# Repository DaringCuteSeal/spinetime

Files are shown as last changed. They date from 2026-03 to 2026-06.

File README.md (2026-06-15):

# Spinetime

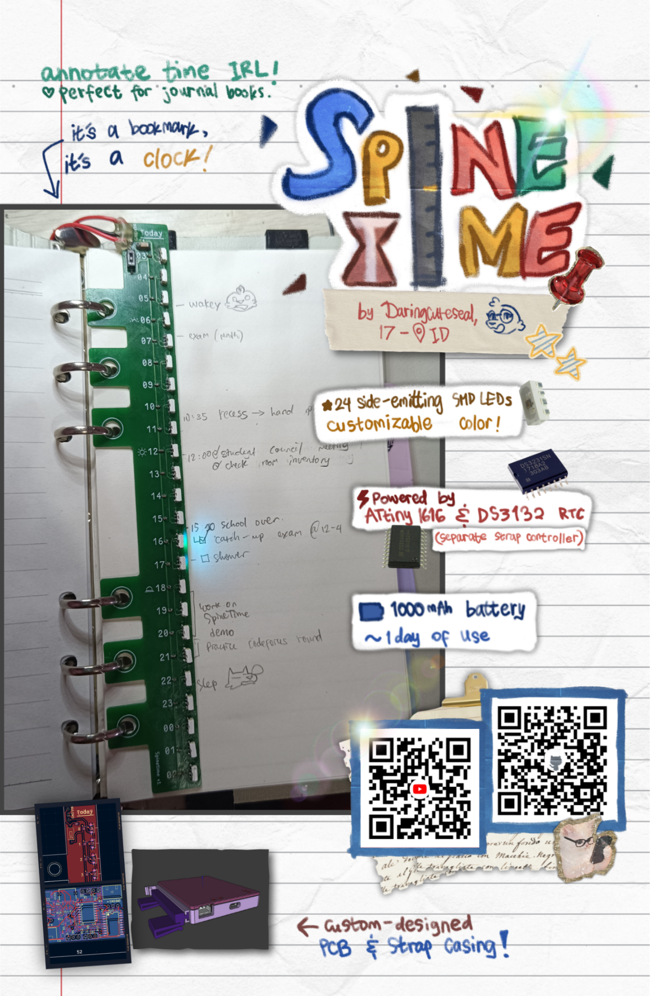
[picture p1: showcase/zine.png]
SpineTime magazine page

[Magazine PDF](showcase/zine.pdf)

[Watch the short demo here!](https://www.youtube.com/shorts/rvpcNDkeEeY)

---

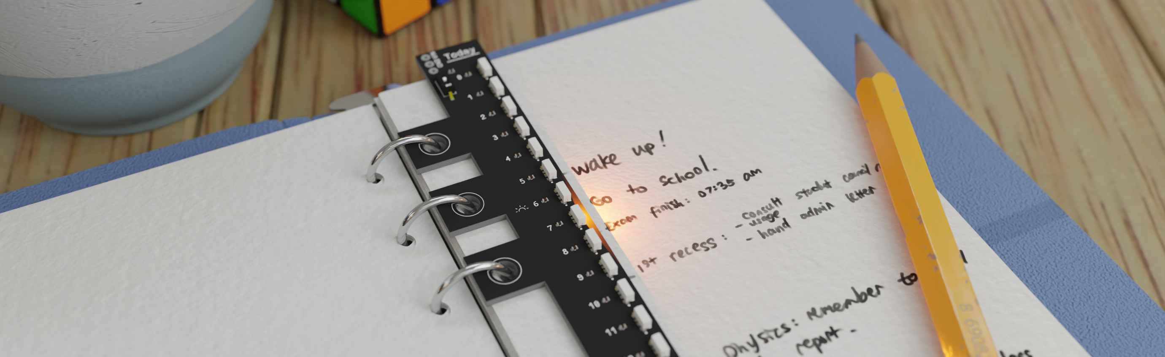
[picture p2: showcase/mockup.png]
Mockup of Spinetime


Spinetime is a ring binder-integrated _linear clock [^1]_ designed to help
students and neurodivergent individuals manage time and tasks more effectively.
Users of Spinetime can visualize the passage of the day at a glance, providing
aid especially for those who struggle with time blindness.

## Why?

It is surprising to me that people have manufactured papers with time table
template, but not invent something as simple as a pointer that tells you how
far you have gone through your table. I suspect that this is because most
people do not experience time blindness, and having some kind of pointer of the
table isn't really all that useful. This is simply not the case for those with
time blindness: **time doesn't really mean anything if presented in the wrong
way.** I hope that the proof of concept that came with Spinetime may help
present time meaningfully for those who struggle with time blindness like me.

## Background

As someone who suffers from time blindness on a daily basis, I find managing my
time extremely challenging. It's been intensely hard to picture how I'll spend
my time for a particular day. Having shuffled between multiple time management
methods, I constantly find myself at home when I plan my day out on my physical
journal. I simply love the tactile feel of using a physical tool to plan out my
day.

However, being the visual-oriented person I am, lacking any visual cue of
"where" in the time dimension I am at any given day has been a major
deal-breaker that has kept me from using physical tools for journalling. Of
course, journalling papers with pre-made time tables exist, but they don't tell
me what time it really is right now in any tangible manner relating to the table
itself—what a bummer.

I've been using [ChronoCat](https://chronocat.app/) (not affiliated) to manage
my time lately, and it's been a perfect digital tool—minimalistic,
very visual, and easy to use. It provides the user with a
time table alongside a visual cue of where they are within the day.
However, like I said before, I crave the tactile feel of physical
note-taking. It'd also be great if I can plan my day without the distraction
that comes with using a full-fledged mobile phone or computer.
Plus, being able to plan my day at school would be a great[^2]. I always
dream that one day, I won't forget several of my appointments again.

I looked at my own journalling book again, and thought: _you know, I
think that ChronoCat's approach doesn't have to be in the form of a
digital app._ And so, I came up with SpineTime.

## How to Use

**Daily use**: simply strap Spinetime to your ring binder by opening the spine and inserting
the linear clock component and start annotating your day. This repository hosts
the A6 binder-compatible
version.

**How to charge the battery**: charge with a type-C cable. 5V, obviously. The controller implements load sharing so you'll be powering the circuit directly with the given 5V when charged.

## How it Works
The LEDs of the bookmark are controlled by a separate controller unit. An ATtiny1616 MCU is used alongside a DS3231 RTC.

## Specs
- Power usage: about 20-25 mA when bookmark is on (3.7V * 25mA = 92.5 mW). Depends on LED color. 7 mA when bookmark is switched off (3.7V * 7mA = 25.9 mW).
- Use duration: about 1d 16h (1000 mAh ÷ 25 mA). Probably a bit lower since we won't (and can't) use the full capacity of the battery.

## Build Instruction
You will need:
1. A soldering iron
2. Solder
3. Everything from [BOM](#BOM)
4. A USB-to-TTL adapter such as a CH340 breakout module
5. Wire crimper
6. Wire stripper
7. Scissors
8. USB-C cable
9. 3 jumper wires (female-to-female)

Steps:
1. Print the [PCBs](#Project-Design-Showcase). Customize if needed. Note that the gerbers aren't included, so you'd have to generate them first from KiCad.
2. Solder components listed on the [BOM](#BOM) according to the PCB file.
3. 3D print the casing components.
4. Use whatever set of cables you have (can be thin) and solder the bookmark's VIN, GND, and DAT through-holes to the cables. Crimp the end into the 3-pin JST housing. Make sure the orientation is aligned correctly with the controller (as JST connectors cannot be plugged in both orientations).
5. Put together everything into the casing: the battery, the controller PCB, and the anti-slip rubbers (might need to be cut to the correct size first, fitting the casing's square indents).
6. If your battery hasn't been crimped yet, crimp the cables to the 2-pin JST. Then plug the battery connector to the controller.
7. Build the [firmware](#firmware). Customize as you wish. You'll need [PlatformIO](https://platformio.org/).
8. FLash the firmware. Initially, set `SET_TIME` to `true` in the `cfg.h` file first to set time, then flash again with `SET_TIME` set to `false`. You will need a USB-to-TTL adapter. Connect the TX pin of the adapter to the TX pin of SpineTime's controller PCB and the RX pin of the adapter to RX. Note that the PCB doesn't have labels for that.. just check the kicad file to know which is which :P. Then, connect the adapter's ground accordingly.
9. You should be done! There's no screw assembly required—everything uses compliant mechanism.

Gotchas:
1. If you can't flash the ATtiny1616, try changing to another device. Initially I couldn't flash my ATtiny and as it turns out, my laptop has a bad USB controller.
2. Some sources online say that SK6812 LEDs are difficult to solder and require lower temp but I found that with hand-soldering, even up to ~350°C is fine. (just don't roast the LEDs for 1 minute straight I guess)

## Spelling
Spinetime, SpineTime, spinetime are all valid. No spineTime or spine_time or anything else.
## Project Design Showcase

### IRL Build

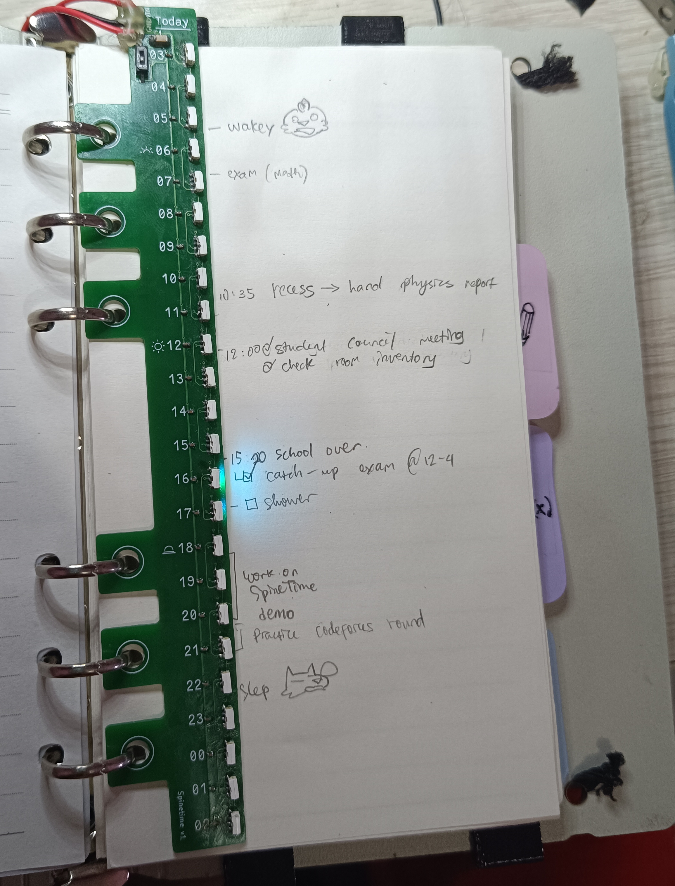
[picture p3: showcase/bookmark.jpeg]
Photo of the bookmark


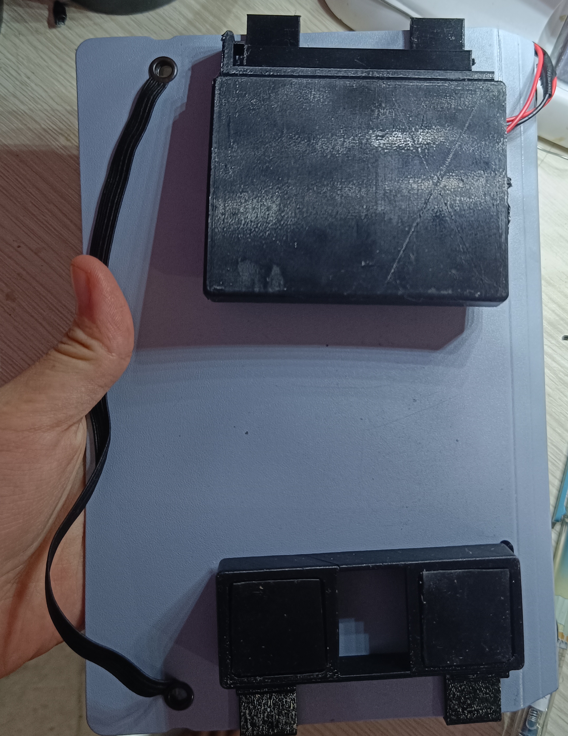
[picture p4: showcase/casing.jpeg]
Photo of the strap casing


Photo of the bookmark being used at a computer lab

Note: I built it with LEDs too big so I didn't put on the casing lid.

### PCBs

The actual bookmark ([project files](kicad/bookmark), [.step file](kicad/bookmark/bookmark.step)):

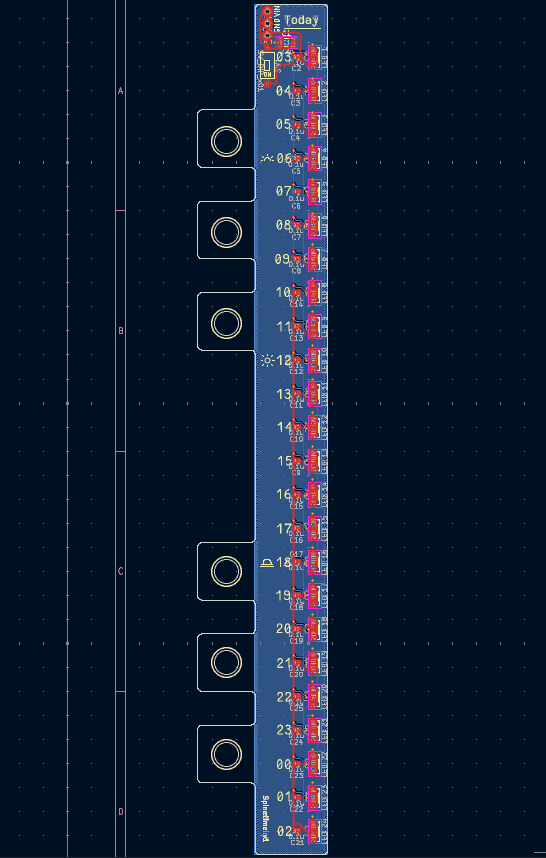
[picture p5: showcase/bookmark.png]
PCB design of bookmark


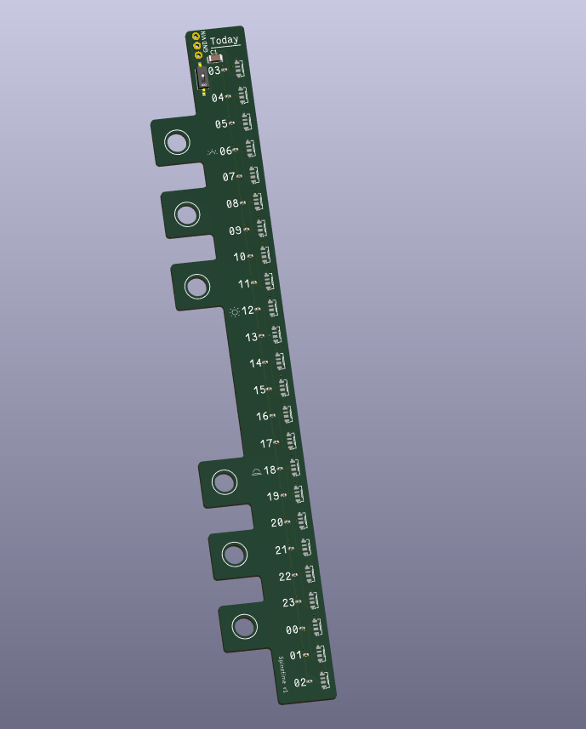
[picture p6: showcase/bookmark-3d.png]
3D PCB design of bookmark


The controller unit ([project files](kicad/controller), [.step file](kicad/controller/controller.step)):
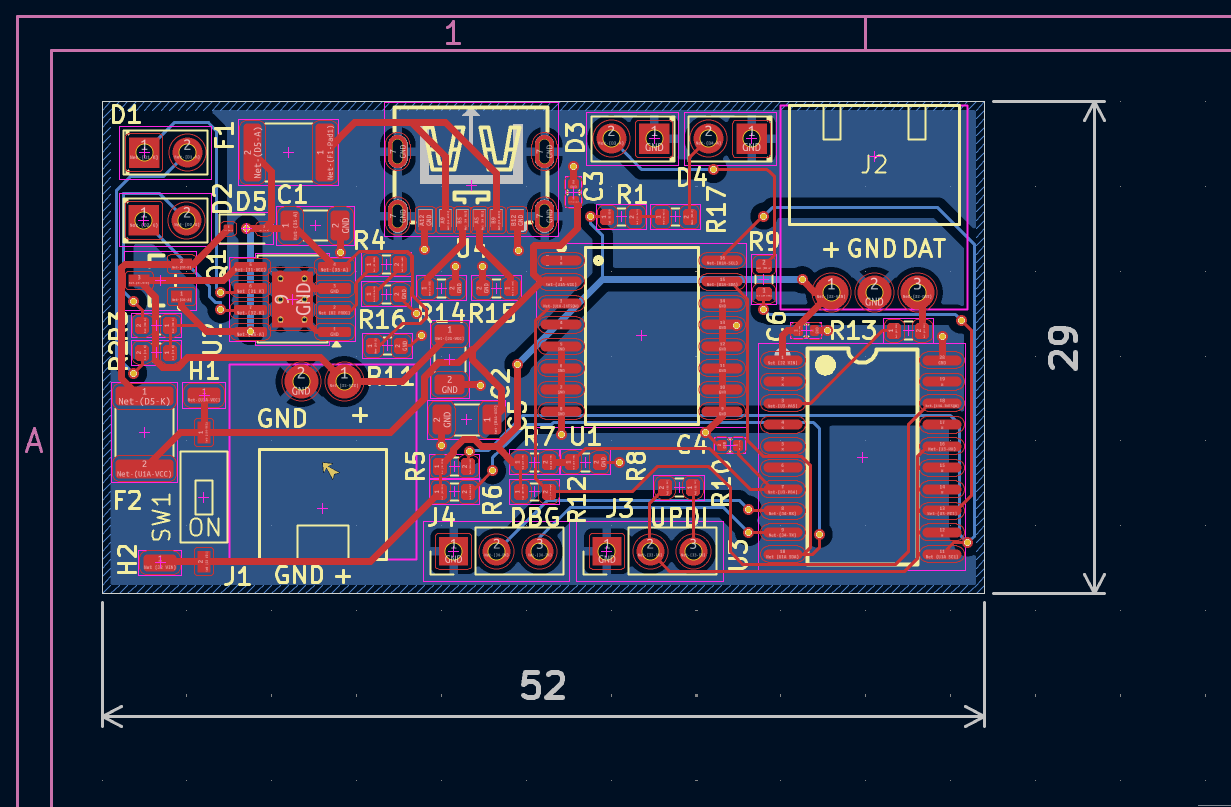
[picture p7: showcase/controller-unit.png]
PCB design of controller unit


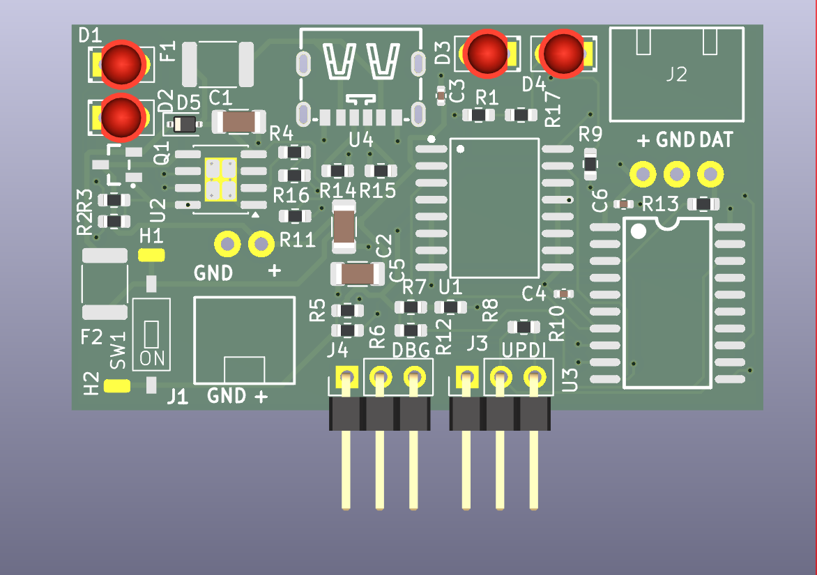
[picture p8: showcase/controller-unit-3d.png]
3D PCB design of controller unit


Schematics:

- [Schematic of controller unit](showcase/controller.pdf)
- [Schematic of bookmark unit](showcase/bookmark.pdf)

### 3D Models

The model files can be found under [freecad/](freecad/).

Casing:
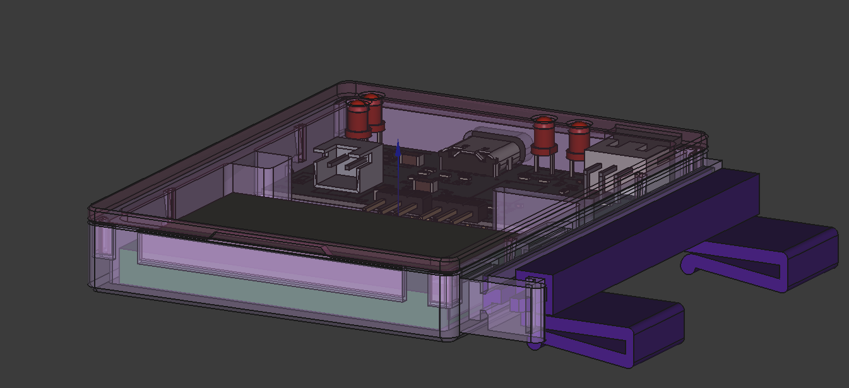
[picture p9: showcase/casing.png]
Casing 3D model


Support clip (so your book cover won't wobble when being written on):
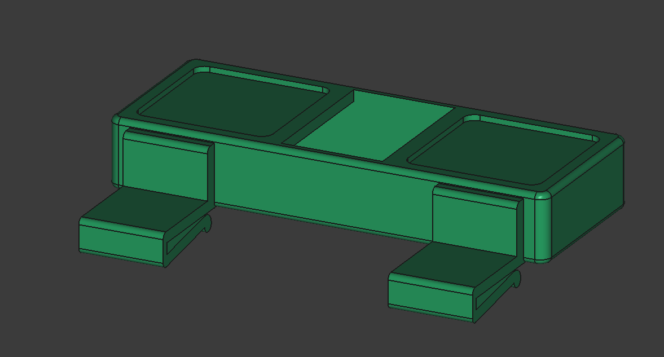
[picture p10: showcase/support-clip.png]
Support clip 3D model


### Firmware
The firmware files for SpineTime, `spinetime-fw`, can be [found in the firmware directory](./firmware).

## BOM
[BOM/bill of materials for this project can be found here](bom/bom.csv).

## Credits

Thanks to [Hack Club](https://hackclub.com/) for supporting! Initially made for [Hack Club Blueprint](https://blueprint.hackclub.com), but later got transferred to [Hack Club Fallout](https://fallout.hackclub.com/).

**Awesome software used:**
- [KiCad](https://www.kicad.org/) (as EDA)
- [Blender](https://www.blender.org/) (for designing mockup)
- [FreeCAD](https://www.freecad.org/) (as CAD)
- [NeoVim](https://neovim.io/) (as IDE)
- [VSCode](https://code.visualstudio.com/) (as IDE)
- [PlatformIO](https://platformio.org/) (as embedded programming platform)
- [Kitty](https://sw.kovidgoyal.net/kitty/) (as terminal)
- [Git](https://git-scm.com/) (as SVC)
- [Artix Linux!](https://artixlinux.org)

**Awesome services used:**
- [Github](.) (hosting project files)

**I used several 3D models for my PCB 3D model:**
- https://grabcad.com/library/usb-type-c-smd-6pin-1
- https://grabcad.com/library/2-pins-jst-1
- https://grabcad.com/library/3-pins-jst-1

**References (unfortunately not all, just the very notable ones):**
- megaTinyCore, awesome core + documentations for my ATTiny: https://github.com/SpenceKonde/megaTinyCore)
- Datasheet of all components I used. I'm not sure if I wanna include all of the links back because I didn't keep track of them, but feel free to ask for the documents I have locally directly to maybe figure out the source.
- NeoPixel guide: https://learn.adafruit.com/adafruit-neopixel-uberguide/logic-level
- Another NeoPixel guide: https://www.digikey.com/en/maker/projects/adafruit-neopixel-berguide/970445a726c1438a9023c1e78c42e0bb
- How to flash ATtiny1616: https://michael-crum.com/attiny1616/
- Changing clock speed of ATtiny1616: https://www.avrfreaks.net/s/topic/a5C3l000000Ubn4EAC/t159058
- Technical problems with SK6812: https://forums.adafruit.com/viewtopic.php?t=188940
- Sk6812 is hard to solder?: https://www.makerfabs.com/blog/post/how-makerfabs-solve-the-oled-sticking-problem
- Order with moisture-sensitive devices recommendations: https://jlcpcb.com/help/article/moisture-sensitivity-level-msl-for-electronic-parts
- Load-sharing circuit: https://www.thanassis.space/loadsharing.html
- SMD resistor guide: https://www.allpcb.com/blog/pcb-assembly/smd-resistors-demystified-sizes-markings-and-practical-applications.html
- Should LED strip's end be connected to anything?: https://www.reddit.com/r/AskElectronics/comments/1bnx4vv/addressable_led_data_out_connect_to_ground_yn/
- TP4056 breakout reference: https://github.com/alltheworld/tp4056/issues/3
- Setting internal reference voltage for attiny1616: https://forum.arduino.cc/t/how-to-measure-supply-voltage-in-attiny/1244260

Huh, am I over-crediting? maybe..
## LLM Usage Disclosure
I used [ChatGPT](https://chatgpt.com) for sanity-checking my configurations (including my controller schematic, for instance it caught that I didn't pull the CC pins to ground).

[^1]: Analog clock that shows time in a linear format, instead of the usual
12-hour wrap-around style. This clock is often suggested for those with ADHD &
time blindness.

[^2]: My school does not allow the use of mobile phone/laptop during class and
recess.

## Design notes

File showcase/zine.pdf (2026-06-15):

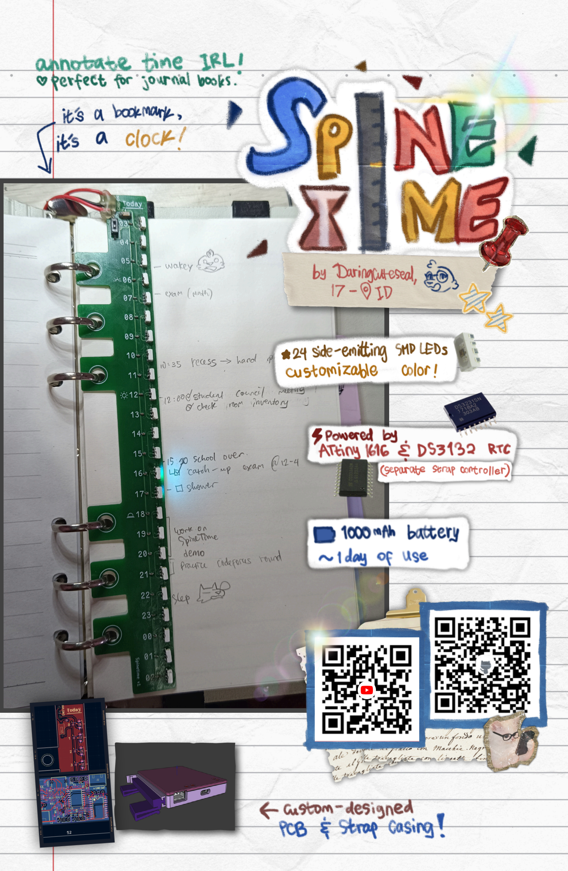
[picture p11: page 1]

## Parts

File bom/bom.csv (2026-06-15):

Index | LCSC# | MPN | Manufacturer | Package | Description | RoHS | Needed | Order Quantity | MOQ | Multiple | Unit Price | Extended Price | Product Link | Already Owned by Daringcuteseal | Note
1 | C382139 | TP4056 | TPOWER | ESOP-8 | Lithium-ion/Polymer ESOP-8 | TRUE | 1 | 5 | 5 | 5 | $0.11830 | $0.59 | https://www.lcsc.com/product-detail/C382139.html | FALSE
2 | C2927026 | USB-TYPE-C-006 | DEALON | SMD | USB-C (USB TYPE-C) Receptacle Connector 6 Position Surface Mount, Right Angle | TRUE | 1 | 10 | 10 | 10 | 9 | $0.49 | https://www.lcsc.com/product-detail/C2927026.html | FALSE
3 | C2830320 | FS8205A | TECH PUBLIC | SOT-23-6 | 20V 9A 1.5W Surface Mount SOT-23-6 | TRUE | 1 | 10 | 10 | 10 | $0.04710 | $0.47 | https://www.lcsc.com/product-detail/C2830320.html | FALSE
4 | C22366440 | DMP1045U-HXY | HXY MOSFET | SOT-23 | P-Channel 20V 5A 1.4W Surface Mount SOT-23 | TRUE | 1 | 10 | 10 | 10 | $0.06240 | $0.62 | https://www.lcsc.com/product-detail/C22366440.html | FALSE
5 | C20996 | SMD1812P075TF | RUILON | 1812 | Polymeric PTC Resettable Fuse 13.2V 750mA Surface Mount 1812 | TRUE | 1 | 5 | 5 | 5 | $0.08730 | $0.44 | https://www.lcsc.com/product-detail/C20996.html | FALSE
6 | C15008 | CL31A107MQHNNNE | Samsung Electro-Mechanics | 1206 | 100uF ±20% 6.3V Ceramic Capacitor X5R 1206 | TRUE | 3 | 10 | 10 | 10 | $0.06810 | $0.68 | https://www.lcsc.com/product-detail/C15008.html | FALSE
7 | C2100 | 1SS404 | JSCJ | SOD-323 | Diode 20V 300mA Surface Mount SOD-323 | TRUE | 1 | 20 | 20 | 20 | $0.0807 | $0.81 | https://www.lcsc.com/product-detail/C2100.html | FALSE
8 | C2937639 | SMD1812P020TF | PTTC(Polytronics Tech) | 1812 | Polymeric PTC Resettable Fuse 30V 200mA Surface Mount 1812 | TRUE | 1 | 10 | 10 | 10 | $0.08940 | $0.89 | https://www.lcsc.com/product-detail/C2937639.html | FALSE
9 | C15401 | 0603WAJ0103T5E | UNI-ROYAL | 603 | 10kΩ ±5% 100mW 0603 Thick Film Resistor | TRUE | 3 | 100 | 100 | 100 | $0.0012 | $0.12 | https://www.lcsc.com/product-detail/C15401.html | FALSE
10 | C23186 | 0603WAF5101T5E | UNI-ROYAL | 603 | 5.1kΩ ±1% 100mW 0603 Thick Film Resistor | TRUE | 2 | 100 | 100 | 100 | $0.00160 | $0.16 | https://www.lcsc.com/product-detail/C23186.html | FALSE
11 | C14675 | RC0603FR-07100KL | YAGEO | 603 | 100mW 100kΩ 75V Thick Film Resistor ±100ppm/℃ ±1% 0603 Chip Resistor - Surface Mount RoHS | TRUE | 1 | 100 | 100 | 100 | $0.00140 | $0.14 | https://www.lcsc.com/product-detail/C14675.html | FALSE
12 | C2890037 | SK6812SIDE-A-RVS | OPSCO Optoelectronics | SMD-4P,4x2mm | SMD-4P,4x2mm LED Addressable, Specialty RoHS | TRUE | 24 | 30 | 5 | 5 | $0.0935 | $2.81 | https://www.lcsc.com/product-detail/C2890037.html | FALSE | Have to buy slightly more than needed. Apparently they’re pain to solder (can break easily when overheated).
13 | C2680613 | CHS-01TB | Nidec | SMD | Dip Switch SPST 1 Position 100mA 6V | TRUE | 2 | 2 | 1 | 1 | $0.97000 | $1.94 | https://www.lcsc.com/product-detail/C2680613.html | FALSE
14 | C2907002 | FRC0603F1001TS | FOJAN | 603 | 1kΩ ±1% 100mW 0603 Thick Film Resistor | TRUE | 6 | 100 | 100 | 100 | $0.00100 | $0.10 | https://www.lcsc.com/product-detail/C2907002.html | FALSE
15 | C614136 | ATTINY1616-SN | MICROCHIP | SOIC-20-300mil | AVR 8 Bit 20MHz 18 SOIC-20-300mil Microcontrollers RoHS | TRUE | 1 | 1 | 1 | 1 | $2.70710 | $2.71 | https://www.lcsc.com/product-detail/C614136.html | FALSE
16 | C9866 | DS3231SN#T&R | MAXIM | SOIC-16-300mil | Built-in Yes SOIC-16-300mil Real Time Clocks RoHS | TRUE | 1 | 1 | 1 | 1 | $5.3424 | $5.34 | https://www.lcsc.com/product-detail/C9866.html | FALSE
17 | C105875 | RC0402FR-07330RL | YAGEO | 402 | 330Ω 62.5mW 50V Thick Film Resistor ±100ppm/℃ ±1% 0402 Chip Resistor - Surface Mount RoHS | TRUE | 1 | 100 | 100 | 100 | 0.0009 | $0.09 | https://www.lcsc.com/product-detail/C105875.html | FALSE
18 | C51048328 | FRC0603F7873TS | FOJAN | 603 | 100mW 787kΩ 75V Thick Film Resistor ±400ppm/℃ ±1% 0603 Chip Resistor - Surface Mount RoHS | TRUE | 1 | 100 | 100 | 100 | 0.0012 | $0.12 | https://www.lcsc.com/product-detail/C51048328.html | FALSE
19 | C2906866 | FRC0402F2003TS | FOJAN | 402 | 200kΩ ±1% 62.5mW 0402 Thick Film Resistor | TRUE | 1 | 100 | 100 | 100 | 0.0007 | $0.07 | https://www.lcsc.com/product-detail/C2906866.html | FALSE
20 | C60474 | CC0402KRX7R7BB104 | YAGEO | 402 | 100nF ±10% 16V Ceramic Capacitor X7R 0402 | TRUE | 27 | 100 | 100 | 100 | $0.00110 | $0.11 | https://www.lcsc.com/product-detail/C60474.html | FALSE
21 |  |  | JLCPCB | 27*177 mm^2 | Bookmark FR4 PCB printing: 27 mm*177 mm, Industrial/Consumer electronics, single PCB, no stackup, white silkscreen, tented via covering, deburring, without gold fingers, without castellated holes, no PCB marking, IPC class 2 standard appearance quality, ink-jet/screen printing silkscreen, without inspection report, without humidity indicator card, 3d build time, 1 layer, 1 design, 1mm thickness, green color, FR4 TG135 material, leaded HASL surface finish, 1 oz outer copper weight, without electrical testing, without edge plating, without paper between PCBs, without confirmation of production file, package box with JLCPCB logo, without UL marking. | FALSE | 1 | 5 | 5 | 5 | unavailable | $5.90 | https://jlcpcb.com/pcb-fabrication/fr4-pcb | FALSE
22 |  |  | JLCPCB | 52*29 mm^2 | Controller unit FR4 PCB printing: 52 mm*29 mm, Industrial/Consumer electronics, single PCB, no stackup, white silkscreen, tented via covering, deburring, without gold fingers, without castellated holes, no PCB marking, 0.3 mm/(0.4/0.45 mm) minimum via hole size/diameter, without 4-wire Kelvin Test, IPC class 2 standard appearance quality, ink-jet/screen printing silkscreen, without inspection report, without humidity indicator card, 2d build time, 2 layers, 1 design, 0.8mm thickness, green color, FR4 TG135 material, leaded HASL surface finish, 1 oz outer copper weight, without electrical testing, without edge plating, without blind slot, without paper between PCBs, without confirmation of production file, package box with JLCPCB logo, board ± 0.2mm outline tolerance, without countersink hole, without UL marking. | FALSE | 1 | 5 | 5 | 5 | unavailable | $2.10 | https://jlcpcb.com/pcb-fabrication/fr4-pcb | FALSE
23 |  |  | Unknown | 523450 | 1000 mAh 523450 3.7V li-po battery with built-in BMS | Unknown | 1 | 1 | 1 | 1 | Rp79,900 | Rp79,900 | https://shopee.co.id/product/19839879/26426877851 | FALSE
24 |  |  | Unknown | XH2.54 | Right-angled 2.54 pitch JST connector, 2 pins | Unknown | 1 | 70 | 70 | 1 | Rp300 | Rp21,000 | https://shopee.co.id/product/46203672/18744978386 | TRUE
25 |  |  | Unknown | XH2.54 | Right-angled 2.54 pitch JST connector, 3 pins | Unknown | 1 | 70 | 70 | 1 | Rp300 | Rp21,000 | https://shopee.co.id/product/46203672/19344978895 | TRUE
26 |  |  | Unknown | 3mm THT | 3mm diffused LED red (used for charging indicator and power indicator) | Unknown | 2 | 10 | 10 | 1 | Rp250 | Rp2,500 | https://shopee.co.id/product/2178321/3603345969/ | TRUE
27 |  |  | Unknown | 3mm THT | 3mm diffused LED yellow (used for low battery warning and debugging) | Unknown | 1 | 10 | 10 | 1 | Rp250 | Rp2,500 | https://shopee.co.id/product/2178321/294292043/ | TRUE
28 |  |  | Unknown | 3mm THT | 3mm diffused LED green (used for full battery indicator) | Unknown | 1 | 10 | 10 | 1 | Rp250 | Rp2,500 | https://shopee.co.id/product/2178321/3603345974/ | TRUE
29 |  |  | Unknown | 5cm*5cm | Rubber sheet for anti-slipping | Unknown | 1 | 7 | 7 | 1 | Rp1,527 | Rp10,689 | https://shopee.co.id/product/274611018/28530490992 | FALSE
30 |  |  | PegangInd |  | 3D printing service with PETG filament | Unknown | 39 | 39 | 1 | 1 | Rp799 | Rp31,161 | https://shopee.co.id/product/234204219/26236129391 | FALSE | Nice cheap local printing service. Price is in per gram of filament (includes extra filament for support).
31 |  |  |  |  | Shipping fee (SF International Standard Express) |  |  |  |  |  | $23.99 | $23.99

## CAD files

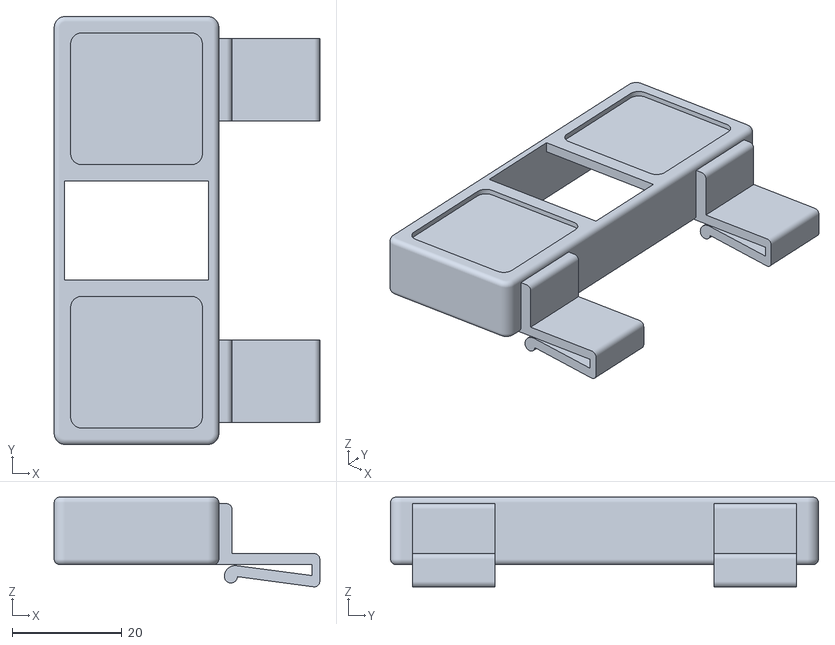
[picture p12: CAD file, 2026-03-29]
freecad/support-clip.stl
48.4 x 78.0 x 16.4

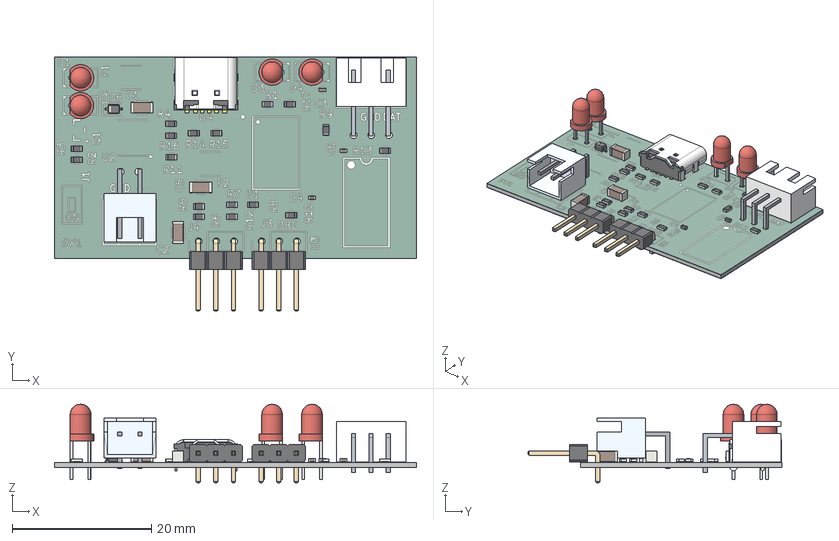
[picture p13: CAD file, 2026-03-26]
kicad/controller/controller.step
52.0 x 36.5 x 11.3 mm
Bileşen1
Bileşen3
Bileşen004
LED_D3.0mm x 4
PinHeader_1x03_P2.54mm_Horizontal x 2
R_0603_1608Metric x 17
D_SOD-323
C_1206_3216Metric x 3
Bileşen008
Bileşen009
Bileşen2.001
Bileşen010
C_0402_1005Metric x 3
USB_type_C_smd_6p
controller_silkscreen
controller_soldermask x 2
controller_PCB

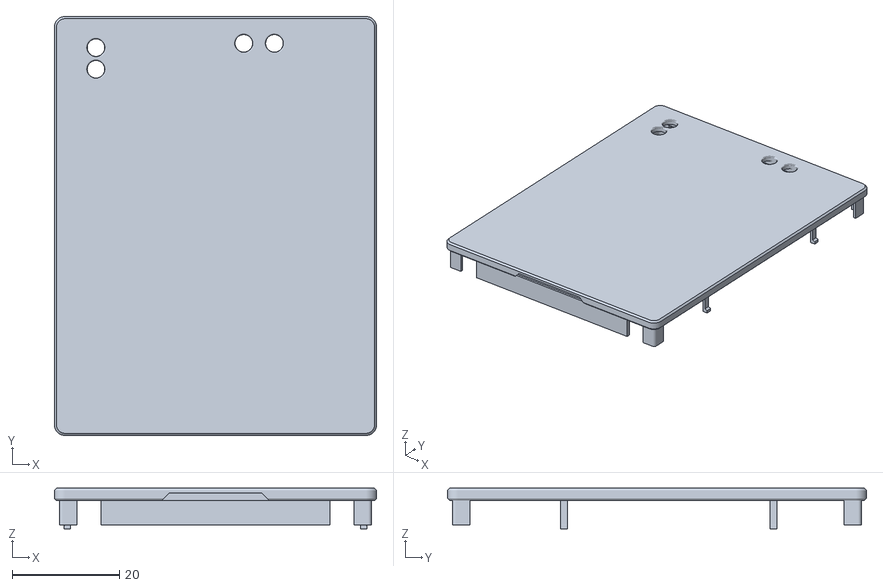
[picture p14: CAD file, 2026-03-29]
freecad/lid.stl
60.0 x 78.0 x 7.58

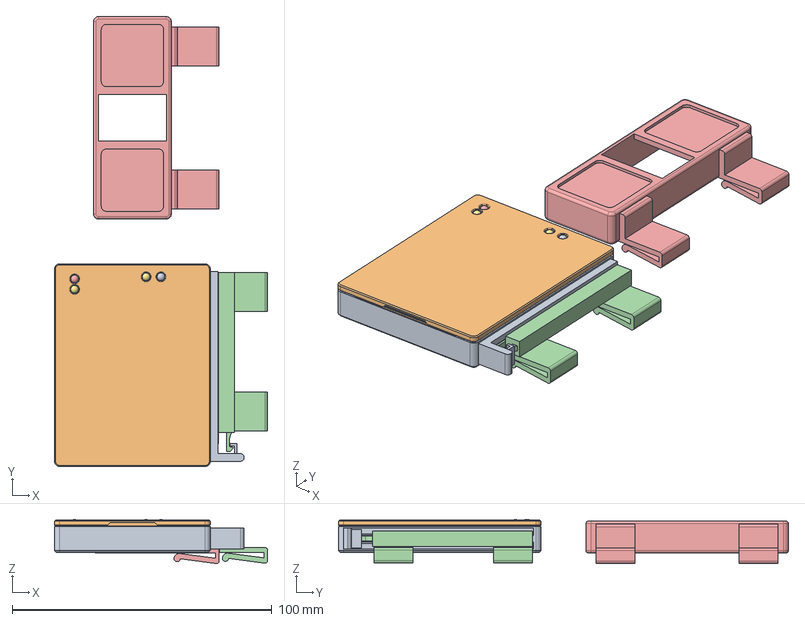
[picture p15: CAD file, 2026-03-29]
freecad/models.FCStd
82.0 x 173.2 x 17.0 mm
casing
lid
battery
BileÃ Âen1
BileÃ Âen3
BileÃ Âen004
LED_D3.0mm
PinHeader_1x03_P2.54mm_Horizontal
LED_D3.0mm001
R_0603_1608Metric
R_0603_1608Metric001
R_0603_1608Metric002
R_0603_1608Metric003
R_0603_1608Metric004
R_0603_1608Metric005
PinHeader_1x03_P2.54mm_Horizontal001
D_SOD-323
R_0603_1608Metric006
R_0603_1608Metric007
C_1206_3216Metric
LED_D3.0mm002
BileÃ Âen008
BileÃ Âen009
BileÃ Âen2.001
BileÃ Âen010
C_0402_1005Metric
R_0603_1608Metric008
R_0603_1608Metric009
R_0603_1608Metric010
C_0402_1005Metric001
LED_D3.0mm003
R_0603_1608Metric011
R_0603_1608Metric012
R_0603_1608Metric013
USB_type_C_smd_6p
USB_type_C_smd_6p001
USB_type_C_smd_6p002
USB_type_C_smd_6p003
C_1206_3216Metric001
R_0603_1608Metric014
R_0603_1608Metric015
R_0603_1608Metric016
C_0402_1005Metric002
C_1206_3216Metric002
controller_silkscreen
controller_silkscreen001
controller_silkscreen002
controller_silkscreen003
controller_silkscreen004
controller_silkscreen005
controller_silkscreen006
controller_silkscreen007
controller_silkscreen008
controller_silkscreen009
controller_silkscreen010
controller_silkscreen011
controller_silkscreen012
controller_silkscreen013
controller_silkscreen014
controller_silkscreen015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

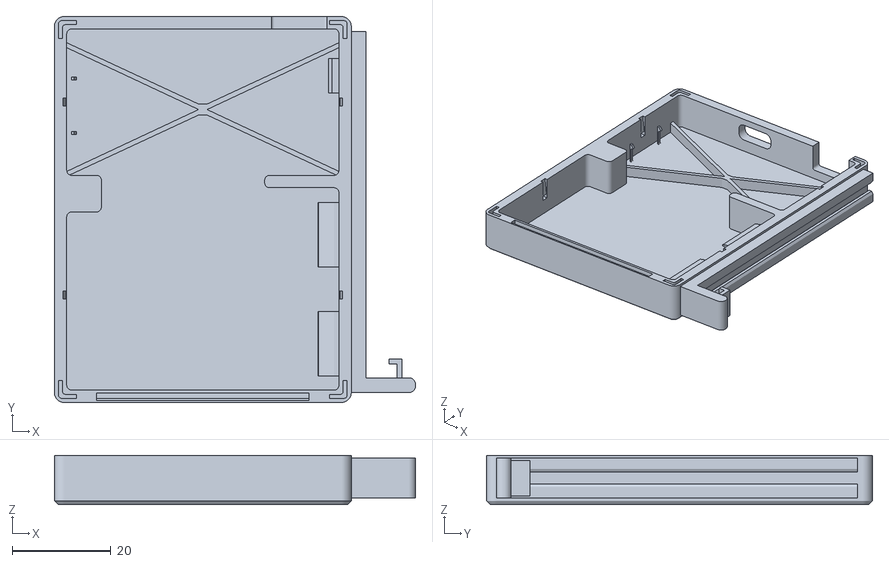
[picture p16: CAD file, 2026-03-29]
freecad/casing.stl
73.0 x 78.0 x 10.0

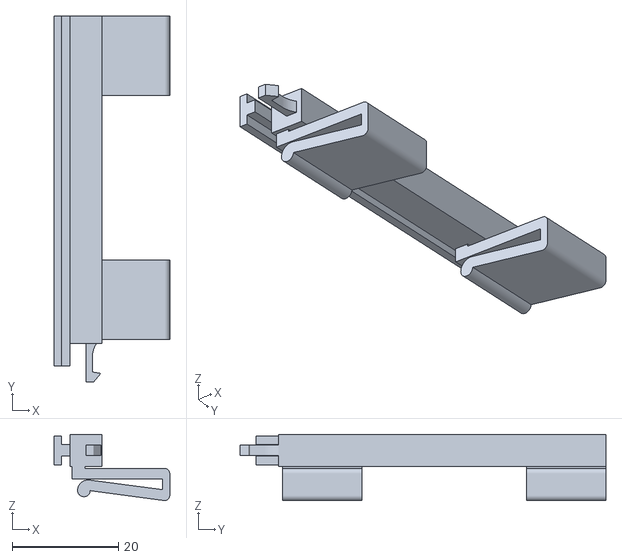
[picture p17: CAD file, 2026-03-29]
freecad/casing-clip.stl
21.8 x 69.0 x 12.5

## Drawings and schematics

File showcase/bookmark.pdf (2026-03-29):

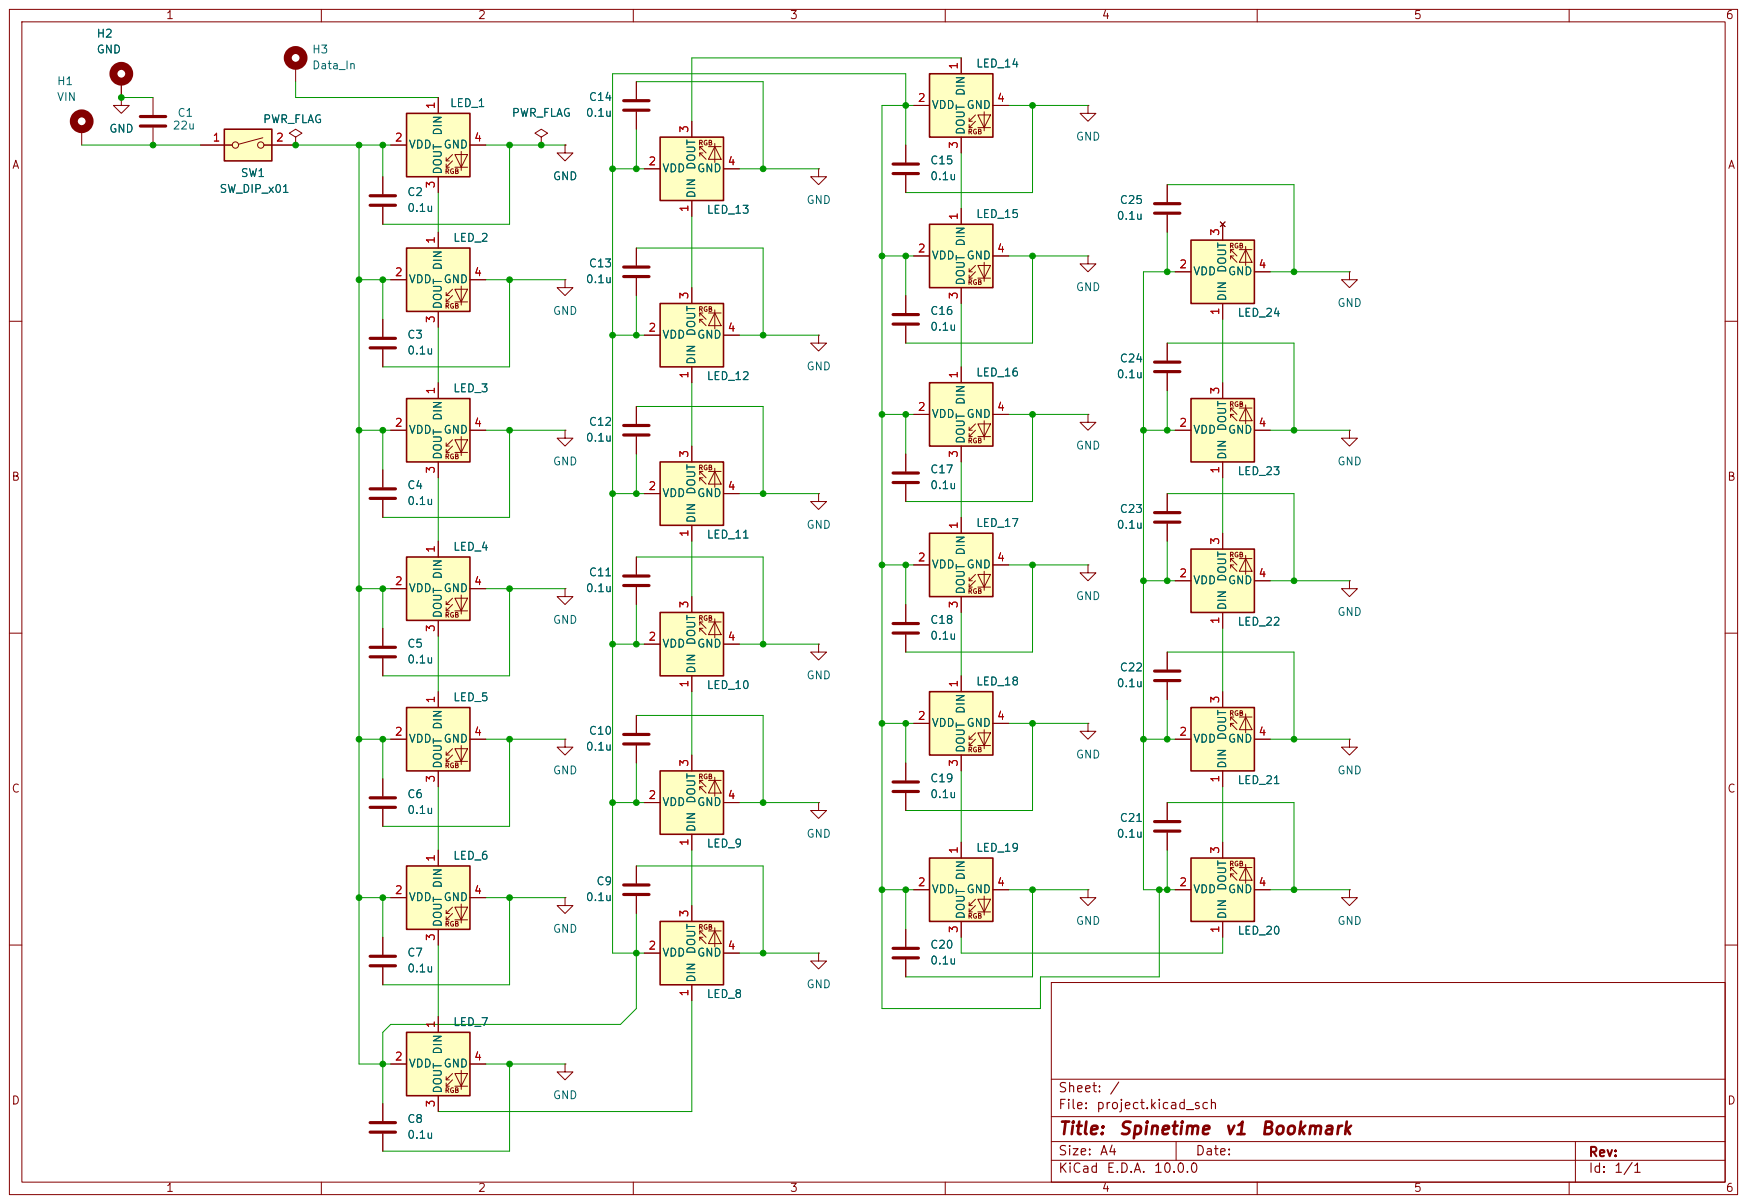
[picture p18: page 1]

Size: A4 | Rev:
KiCad E.D.A. 10.0.0 | Id: 1/1

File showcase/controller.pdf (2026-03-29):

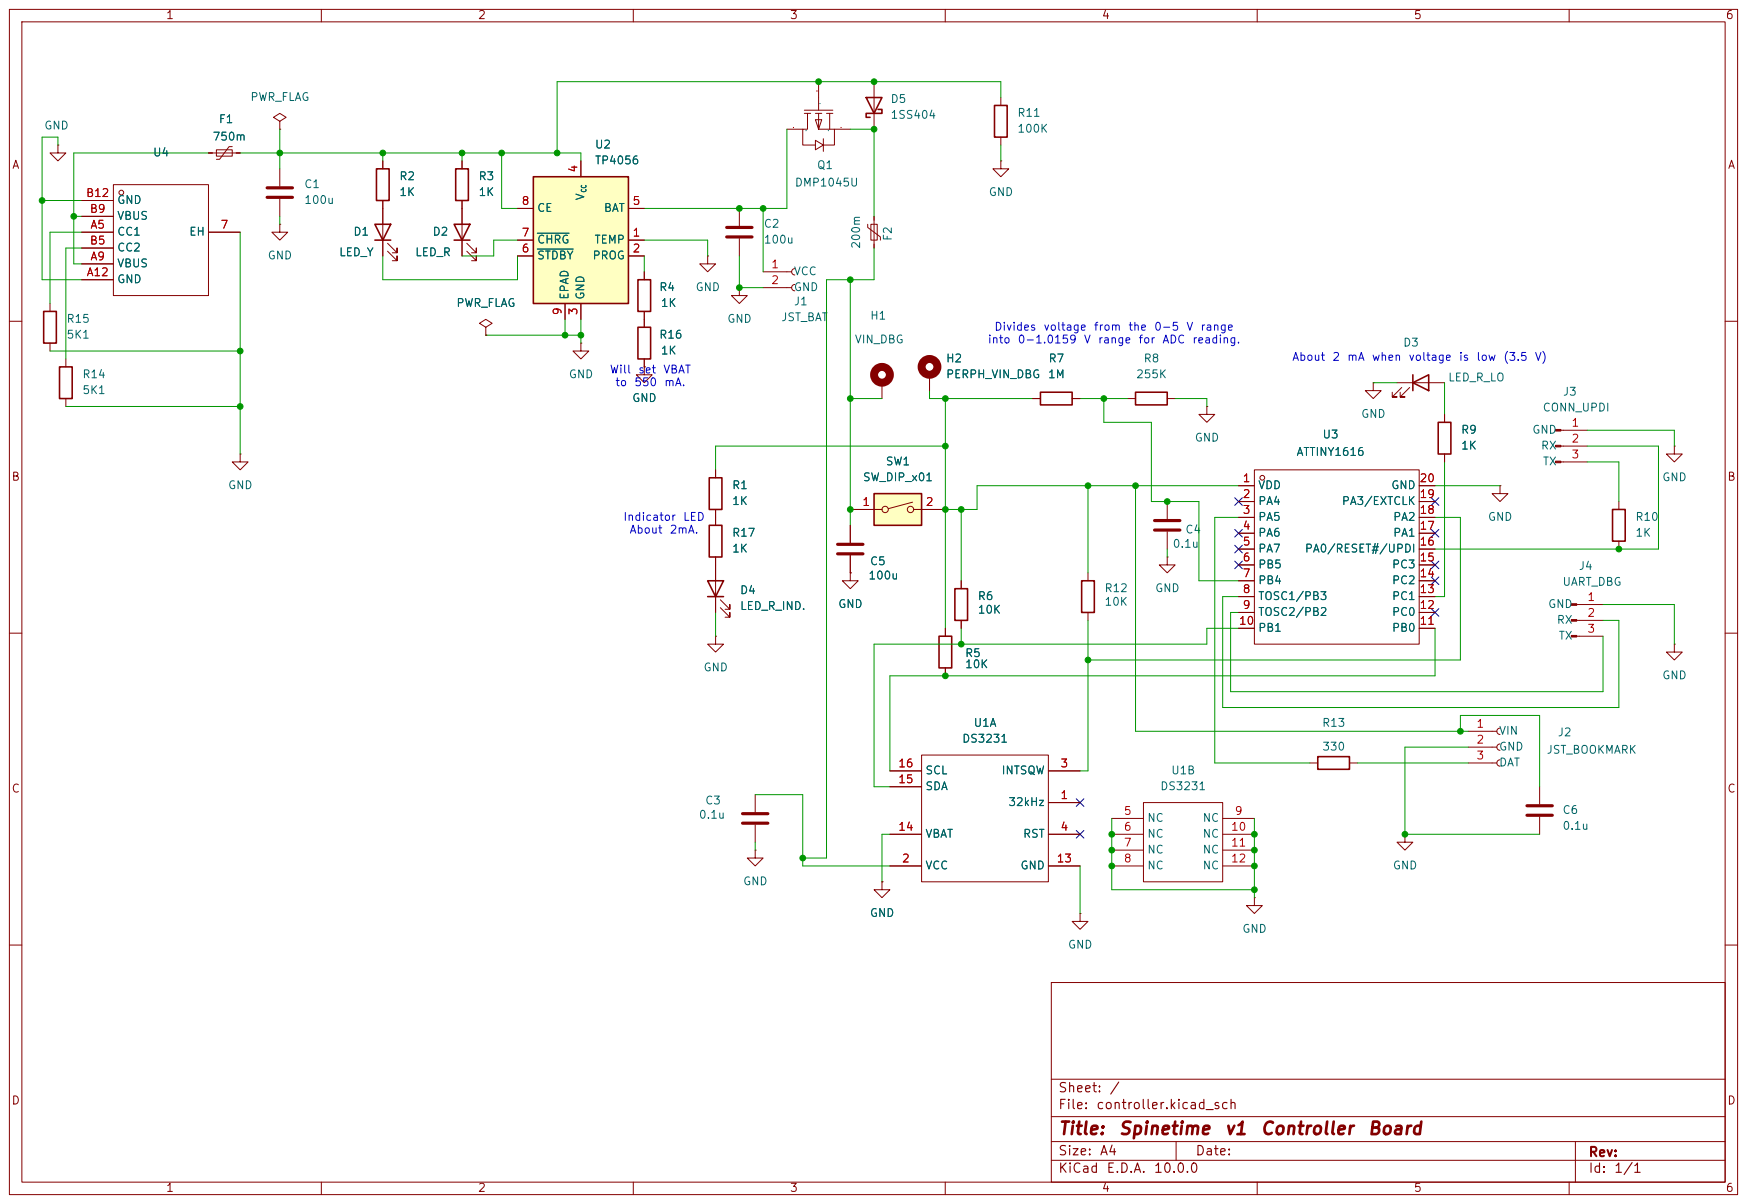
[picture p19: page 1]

Divides voltage from the 0-5 V range
into 0-1.0159 V range for ADC reading.

About 2 mA when voltage is low (3.5 V)

About 2mA. Will set VBAT

Sheet: /
File: controller.kicad_sch
Title: Spinetime v1 Controller Board

Size: A4 | Rev:
KiCad E.D.A. 10.0.0 | Id: 1/1

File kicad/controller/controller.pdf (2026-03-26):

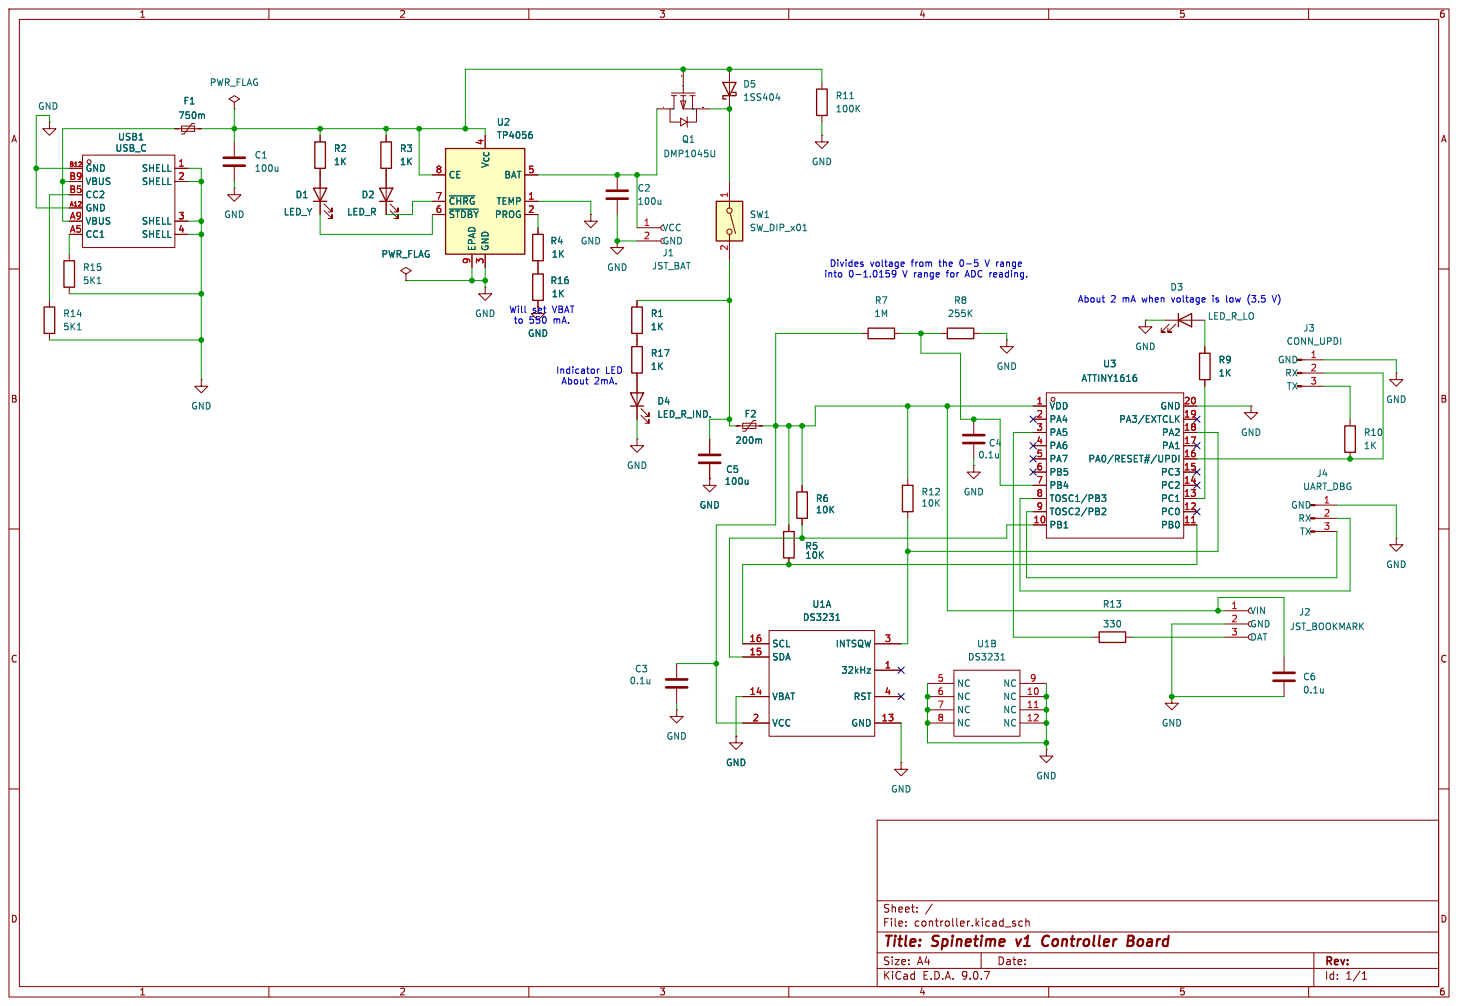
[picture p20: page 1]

File: controller.kicad_sch Sheet: /
Id: 1/1 Title: Spinetime v1 Controller Board

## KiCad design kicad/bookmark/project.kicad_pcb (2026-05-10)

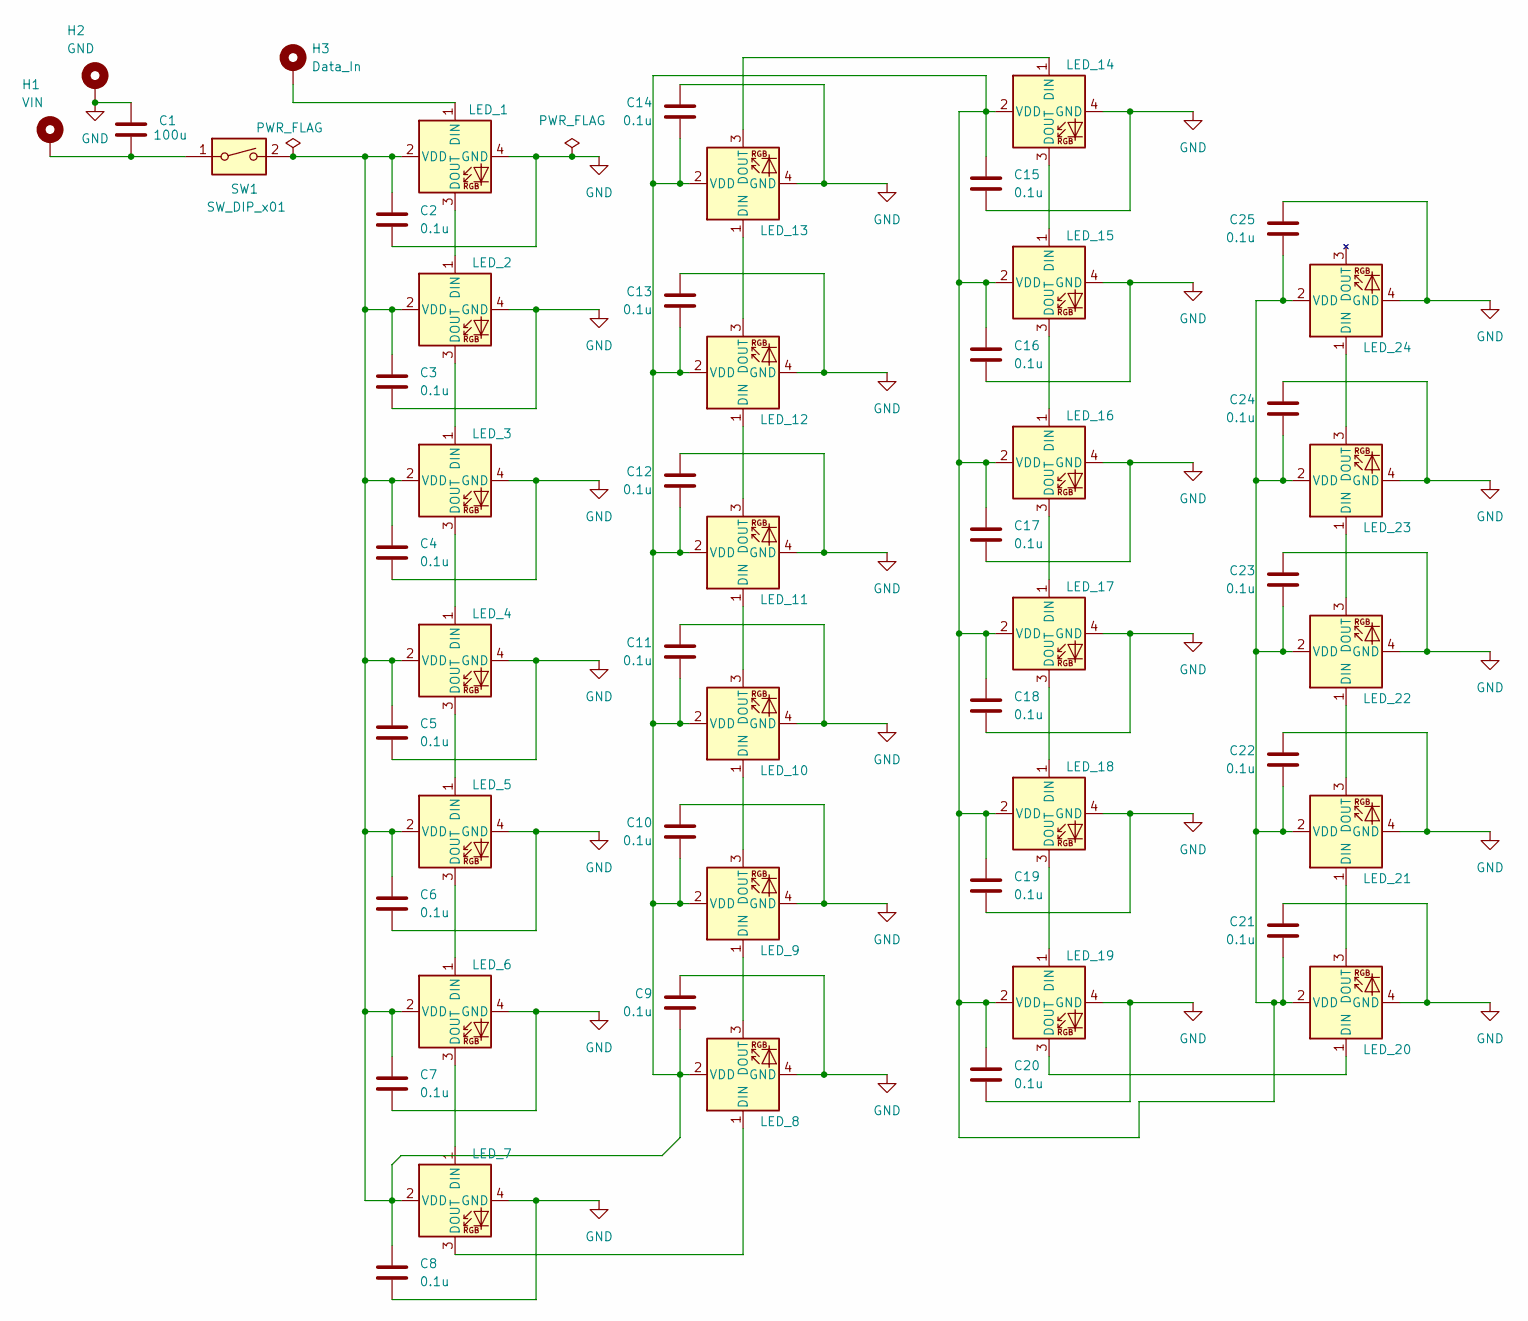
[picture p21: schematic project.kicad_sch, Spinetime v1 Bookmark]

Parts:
C1: 100u; C_1206_3216Metric
C2, C3, C4, C5, C6, C7, C8, C9, C10, C11, C12, C13, C14, C15, C16, C17, C18, C19, C20, C21, C22, C23, C24, C25: 0.1u; C_0402_1005Metric
D1: LED_1; LED-SMD_4P-L4.0-W1.6-L
D2: LED_2; LED-SMD_4P-L4.0-W1.6-L
D3: LED_3; LED-SMD_4P-L4.0-W1.6-L
D4: LED_4; LED-SMD_4P-L4.0-W1.6-L
D5: LED_5; LED-SMD_4P-L4.0-W1.6-L
D6: LED_6; LED-SMD_4P-L4.0-W1.6-L
D7: LED_7; LED-SMD_4P-L4.0-W1.6-L
D8: LED_8; LED-SMD_4P-L4.0-W1.6-L
D9: LED_9; LED-SMD_4P-L4.0-W1.6-L
D10: LED_10; LED-SMD_4P-L4.0-W1.6-L
D11: LED_11; LED-SMD_4P-L4.0-W1.6-L
D12: LED_12; LED-SMD_4P-L4.0-W1.6-L
D13: LED_13; LED-SMD_4P-L4.0-W1.6-L
D14: LED_14; LED-SMD_4P-L4.0-W1.6-L
D15: LED_15; LED-SMD_4P-L4.0-W1.6-L
D16: LED_16; LED-SMD_4P-L4.0-W1.6-L
D17: LED_17; LED-SMD_4P-L4.0-W1.6-L
D18: LED_18; LED-SMD_4P-L4.0-W1.6-L
D19: LED_19; LED-SMD_4P-L4.0-W1.6-L
D20: LED_20; LED-SMD_4P-L4.0-W1.6-L
D21: LED_21; LED-SMD_4P-L4.0-W1.6-L
D22: LED_22; LED-SMD_4P-L4.0-W1.6-L
D23: LED_23; LED-SMD_4P-L4.0-W1.6-L
D24: LED_24; LED-SMD_4P-L4.0-W1.6-L
H1: VIN; THT_hole_2mm
H2: GND; THT_hole_2mm
H3: Data_In; THT_hole_2mm
SW1: SW_DIP_x01; SW-SMD_CHS-01B

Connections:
GND: C1.1, C2.2, C3.2, C4.2, C5.2, C6.2, C7.2, C8.2, C9.2, C10.2, C11.2, C12.2, C13.2, C14.2, C15.2, C16.2, C17.2, C18.2, C19.2, C20.2, C21.2, C22.2, C23.2, C24.2, C25.2, D1.4 (GND), D2.4 (GND), D3.4 (GND), D4.4 (GND), D5.4 (GND), D6.4 (GND), D7.4 (GND), D8.4 (GND), D9.4 (GND), D10.4 (GND), D11.4 (GND), D12.4 (GND), D13.4 (GND), D14.4 (GND), D15.4 (GND), D16.4 (GND), D17.4 (GND), D18.4 (GND), D19.4 (GND), D20.4 (GND), D21.4 (GND), D22.4 (GND), D23.4 (GND), D24.4 (GND), H2.1 (1_1)
unnamed: C1.2, H1.1 (1_1), SW1.1
unnamed: D1.1 (DIN), H3.1 (1_1)
unnamed: D1.3 (DOUT), D2.1 (DIN)
unnamed: C2.1, C3.1, C4.1, C5.1, C6.1, C7.1, C8.1, C9.1, C10.1, C11.1, C12.1, C13.1, C14.1, C15.1, C16.1, C17.1, C18.1, C19.1, C20.1, C21.1, C22.1, C23.1, C24.1, C25.1, D1.2 (VDD), D2.2 (VDD), D3.2 (VDD), D4.2 (VDD), D5.2 (VDD), D6.2 (VDD), D7.2 (VDD), D8.2 (VDD), D9.2 (VDD), D10.2 (VDD), D11.2 (VDD), D12.2 (VDD), D13.2 (VDD), D14.2 (VDD), D15.2 (VDD), D16.2 (VDD), D17.2 (VDD), D18.2 (VDD), D19.2 (VDD), D20.2 (VDD), D21.2 (VDD), D22.2 (VDD), D23.2 (VDD), D24.2 (VDD), SW1.2
unnamed: D2.3 (DOUT), D3.1 (DIN)
unnamed: D3.3 (DOUT), D4.1 (DIN)
unnamed: D4.3 (DOUT), D5.1 (DIN)
unnamed: D5.3 (DOUT), D6.1 (DIN)
unnamed: D6.3 (DOUT), D7.1 (DIN)
unnamed: D7.3 (DOUT), D8.1 (DIN)
unnamed: D8.3 (DOUT), D9.1 (DIN)
unnamed: D9.3 (DOUT), D10.1 (DIN)
unnamed: D10.3 (DOUT), D11.1 (DIN)
unnamed: D11.3 (DOUT), D12.1 (DIN)
unnamed: D12.3 (DOUT), D13.1 (DIN)
unnamed: D13.3 (DOUT), D14.1 (DIN)
unnamed: D14.3 (DOUT), D15.1 (DIN)
unnamed: D15.3 (DOUT), D16.1 (DIN)
unnamed: D16.3 (DOUT), D17.1 (DIN)
unnamed: D17.3 (DOUT), D18.1 (DIN)
unnamed: D18.3 (DOUT), D19.1 (DIN)
unnamed: D19.3 (DOUT), D20.1 (DIN)
unnamed: D20.3 (DOUT), D21.1 (DIN)
unnamed: D21.3 (DOUT), D22.1 (DIN)
unnamed: D22.3 (DOUT), D23.1 (DIN)
unnamed: D23.3 (DOUT), D24.1 (DIN)

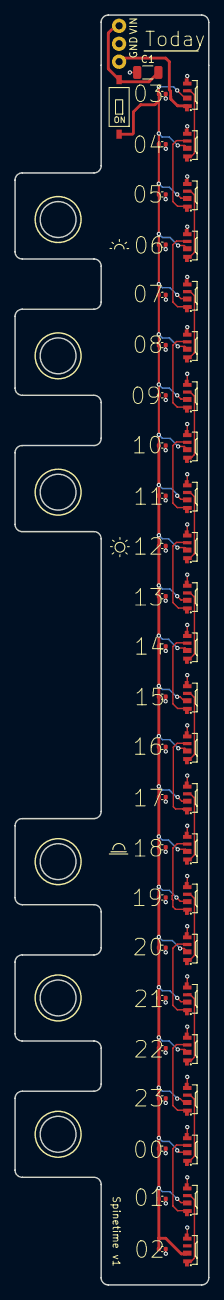
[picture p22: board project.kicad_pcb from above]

Board: 2 copper layers, 27.0 x 177.0 mm, 53 parts (0 on the bottom side), 27 nets.

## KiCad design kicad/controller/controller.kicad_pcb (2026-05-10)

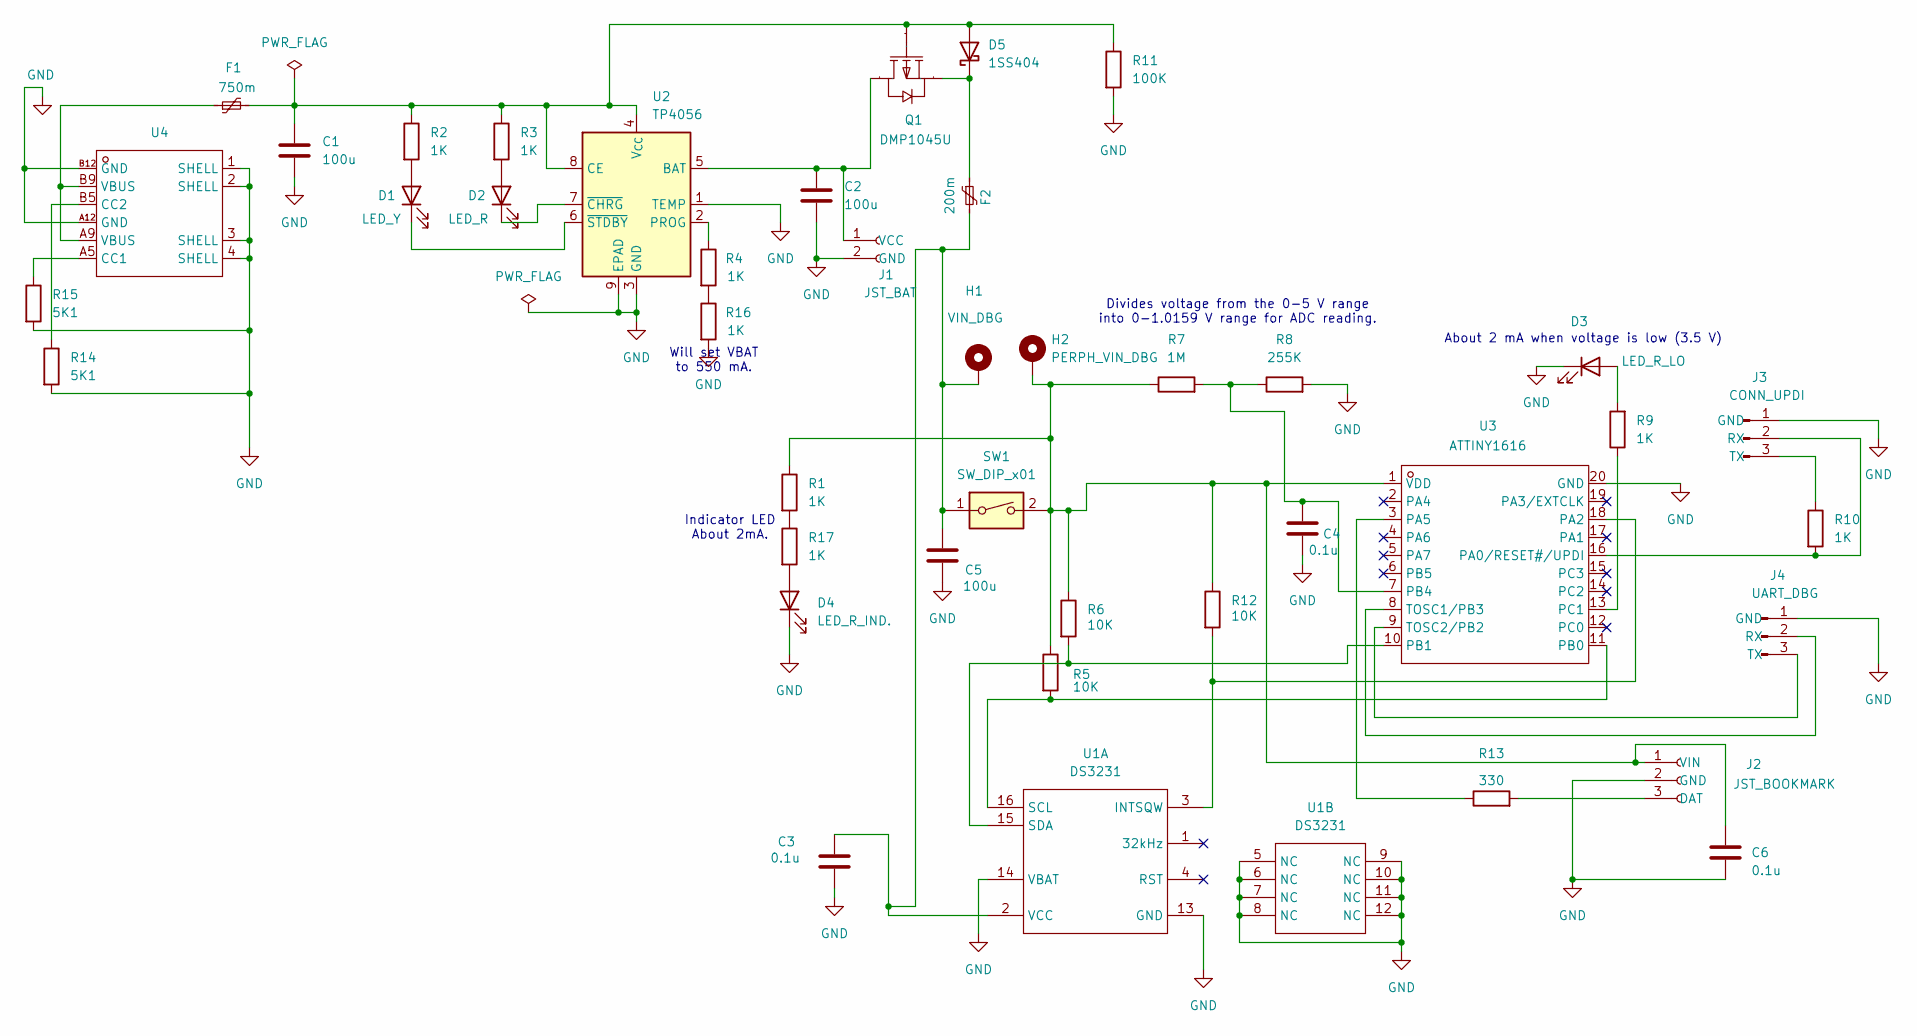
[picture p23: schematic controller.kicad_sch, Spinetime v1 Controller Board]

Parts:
C1, C2, C5: 100u; C_1206_3216Metric
C3, C4, C6: 0.1u; C_0402_1005Metric
D1: LED_Y; LED_D2.0mm_W4.8mm_H2.5mm_FlatTop
D2: LED_R; LED_D2.0mm_W4.8mm_H2.5mm_FlatTop
D3: LED_R_LO; LED_D2.0mm_W4.8mm_H2.5mm_FlatTop
D4: LED_R_IND.; LED_D2.0mm_W4.8mm_H2.5mm_FlatTop
D5: 1SS404; D_SOD-323
F1: 750m; Fuse_1812_4532Metric
F2: 200m; Fuse_1812_4532Metric
H1: VIN_DBG; SolderWirePad_1x01_SMD_1x2mm
H2: PERPH_VIN_DBG; SolderWirePad_1x01_SMD_1x2mm
J1: JST_BAT; JST_1x2_2.54mm-horizontal_1
J2: JST_BOOKMARK; JST_1x3_2.54mm-horizontal
J3: CONN_UPDI; PinHeader_1x03_P2.54mm_Vertical
J4: UART_DBG; PinHeader_1x03_P2.54mm_Vertical
Q1: DMP1045U; SOT-23-3_L2.9-W1.5-P1.90-LS2.6-BR; Manufacturer Part DMP1045U-HXY; LCSC Part Name 1个P沟道 耐压:20V 电流:5A
R1, R2, R3, R4, R9, R10, R16, R17: 1K; R_0603_1608Metric
R5, R6, R12: 10K; R_0603_1608Metric
R7: 1M; R_0603_1608Metric
R8: 255K; R_0603_1608Metric
R11: 100K; R_0603_1608Metric
R13: 330; R_0603_1608Metric
R14, R15: 5K1; R_0603_1608Metric
SW1: SW_DIP_x01; SW-SMD_CHS-01B
U1: DS3231; SOIC-16_L10.3-W7.5-P1.27-LS10.3-BL; Manufacturer Part DS3231SN#T&R; LCSC Part Name 超高精度、I²C接口、集成RTC/TCXO/晶体
U2: TP4056; SOIC-8-1EP_3.9x4.9mm_P1.27mm_EP2.41x3.3mm_ThermalVias
U3: ATTINY1616; SOIC-20_L12.8-W7.5-P1.27-LS10.3-BL; Manufacturer Part ATTINY1616-SNR; LCSC Part Name tinyAVR 1系列微控制器
U4: USB-C-SMD_USB-TYPE-C-006; Manufacturer Part USB-TYPE-C-006; LCSC Part Name Type-C 母 卧贴

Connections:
GND: C1.2, C2.2, C3.2, C4.2, C5.2, C6.2, D3.1 (K), D4.1 (K), J1.2 (GND), J2.2 (GND), J3.1 (GND), J4.1 (GND), R8.2, R11.2, R14.2, R15.2, R16.2, U1.5 (NC), U1.6 (NC), U1.7 (NC), U1.8 (NC), U1.9 (NC), U1.10 (NC), U1.11 (NC), U1.12 (NC), U1.13 (GND), U1.14 (VBAT), U2.1 (TEMP), U2.3 (GND), U2.9 (EPAD), U3.20 (GND), U4.1 (SHELL), U4.2 (SHELL), U4.3 (SHELL), U4.4 (SHELL), U4.A12 (GND), U4.B12 (GND)
unnamed: D1.2 (A), R2.2
unnamed: D1.1 (K), U2.6 (~STDBY)
unnamed: D2.2 (A), R3.2
unnamed: D2.1 (K), U2.7 (~CHRG)
unnamed: D3.2 (A), R9.2
unnamed: D4.2 (A), R17.2
unnamed: C1.1, D5.2 (A), F1.2, Q1.1 (G), R2.1, R3.1, R11.1, U2.4 (V_{CC}), U2.8 (CE)
unnamed: D5.1 (K), F2.1, Q1.2 (S)
unnamed: F1.1, U4.A9 (VBUS), U4.B9 (VBUS)
unnamed: C2.1, J1.1 (VCC), Q1.3 (D), U2.5 (BAT)
unnamed: J2.3 (DAT), R13.2
unnamed: C6.1, H2.1 (1_1), J2.1 (VIN), R1.1, R5.1, R6.1, R7.1, R12.1, SW1.2, U3.1 (VDD)
unnamed: J3.2 (RX), R10.2, U3.16 (PA0/RESET#/UPDI)
unnamed: J3.3 (TX), R10.1
unnamed: J4.2 (RX), U3.8 (TOSC1/PB3)
unnamed: J4.3 (TX), U3.9 (TOSC2/PB2)
unnamed: R1.2, R17.1
unnamed: R4.2, R16.1
unnamed: R12.2, U1.3 (INTSQW), U3.18 (PA2)
unnamed: R5.2, U1.16 (SCL), U3.11 (PB0)
unnamed: R6.2, U1.15 (SDA), U3.10 (PB1)
unnamed: C3.1, C5.1, F2.2, H1.1 (1_1), SW1.1, U1.2 (VCC)
unnamed: R4.1, U2.2 (PROG)
unnamed: R13.1, U3.3 (PA5)
unnamed: C4.1, R7.2, R8.1, U3.7 (PB4)
unnamed: R9.1, U3.13 (PC1)
unnamed: R15.1, U4.A5 (CC1)
unnamed: R14.1, U4.B5 (CC2)

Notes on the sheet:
Indicator LED About 2mA.
Divides voltage from the 0-5 V range into 0-1.0159 V range for ADC reading.
Will set VBAT to 550 mA.
About 2 mA when voltage is low (3.5 V)

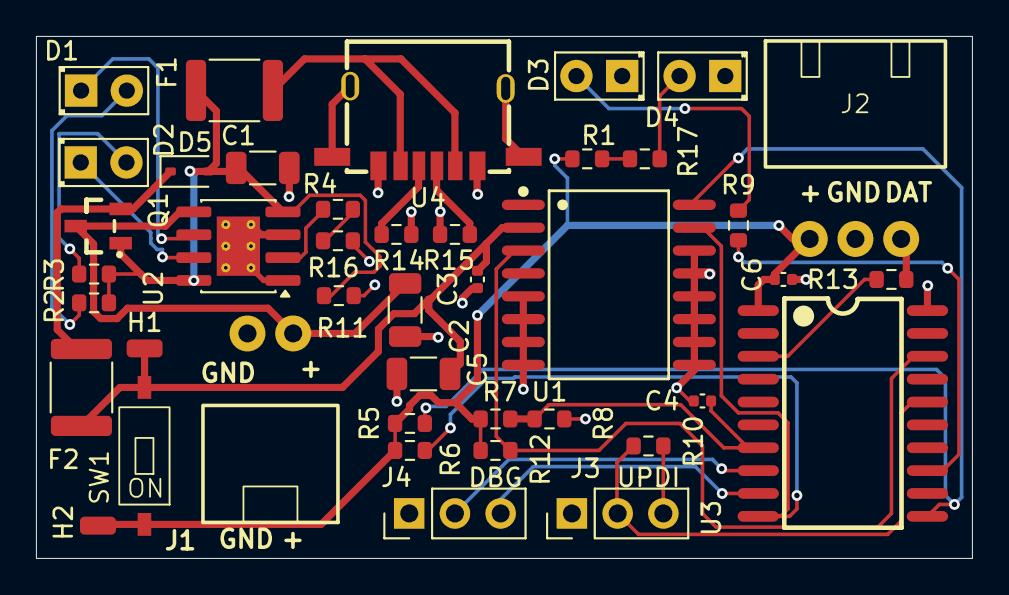
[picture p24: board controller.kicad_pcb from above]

Board: 2 copper layers, 52.0 x 29.0 mm, 42 parts (0 on the bottom side), 29 nets.

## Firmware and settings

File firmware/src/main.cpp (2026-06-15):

/** Copyright 2026 DaringCuteSeal/Cikitta T.
 *
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
 * THE SOFTWARE IS PROVIDED “AS IS”, WITHOUT WARRANTY OF ANY KIND,
 * EXPRESS OR IMPLIED, INCLUDING BUT NOT LIMITED TO THE WARRANTIES OF
 * MERCHANTABILITY, FITNESS FOR A PARTICULAR PURPOSE AND NONINFRINGEMENT. IN NO
 * EVENT SHALL THE AUTHORS OR COPYRIGHT HOLDERS BE LIABLE FOR ANY CLAIM, DAMAGES
 * OR OTHER LIABILITY, WHETHER IN AN ACTION OF CONTRACT, TORT OR OTHERWISE,
 * ARISING FROM, OUT OF OR IN CONNECTION WITH THE SOFTWARE OR THE USE OR OTHER
 * DEALINGS IN THE SOFTWARE.
 */

#include <Arduino.h>
#include <tinyNeoPixel.h>
#include <DS3231-RTC.h>
#include "cfg.h"

constexpr uint8_t RED_STEPS = COLOR_R / 60;
constexpr uint8_t GREEN_STEPS = COLOR_G / 60;
constexpr uint8_t BLUE_STEPS = COLOR_B / 60;

volatile bool isr_is_triggered = false;

tinyNeoPixel led_strip(LED_COUNT, LED_PIN, NEO_GRB + NEO_KHZ800);
DS3231 rtc;
RTClib rtclib;
uint16_t pixelNumber = LED_COUNT;

#if SET_TIME == true
DateTime compile_time(__DATE__, __TIME__);
#endif

#if SET_TIME == true
// Set the time to compilation time.
void set_time()
{
  rtc.setYear(compile_time.getYear() - 2000);
  rtc.setMonth(compile_time.getMonth());
  rtc.setDate(compile_time.getDay());
  rtc.setHour(compile_time.getHour());
  rtc.setMinute(compile_time.getMinute());
  rtc.setSecond(compile_time.getSecond());
  
  DateTime now = rtclib.now();

#if SET_DBG == true
  Serial.println(F("Time has been set to: "));
  Serial.print(now.getYear(), DEC);
  Serial.print("-");
  Serial.print(now.getMonth(), DEC);
  Serial.print("-");
  Serial.print(now.getDay(), DEC);
  Serial.print(" ");
  Serial.print(now.getHour(), DEC);
  Serial.print(":");
  Serial.print(now.getMinute(), DEC);
  Serial.print(":");
  Serial.print(now.getSecond(), DEC);
  Serial.end();
#endif
}
#endif

// Configure the DS3231 real-time system clock.
void configure_rtc()
{
  // Set to 24-hour format
  rtc.setClockMode(false);
}

// sets the ADC voltage resolution
inline void select_adc_res()
{
  ADC0_CTRLA = (ADC0_CTRLA & ~ADC_RESSEL_bm) | ADC_RESSEL_10BIT_gc;
}

// select the correct reference voltage for reading battery level
inline void select_bandgap()
{
  analogReference(INTERNAL1V1);  
}

// enable writing to some locked registers, by writing to the CCP (configuration change protection) register.
inline void unlock_ccp()
{
  CCP = CCP_IOREG_gc;
}

// modulo operator that works with negative numbers.
inline int8_t mod(int8_t a, int8_t b)
{
  if (a >= 0)
    return a % b;
  else
    // -a % b = (b - (a % b)) % b
    return (b - ((-a) % b)) % b;
}

// Set the brown-out detector configuration.
void set_bod_config()
{
  // set brownout detector to sampled when sleeping to save power
  unlock_ccp();
  BOD_CTRLA = (BOD_CTRLA & ~BOD_SLEEP_gm) | BOD_SLEEP_SAMPLED_gc;
}

// Set the LED strip to the correct state based on the hour and minute.
void set_led_strip()
{
  bool tmp;
  int8_t curr_hour = rtc.getHour(tmp, tmp); 
  int8_t curr_min = rtc.getMinute();

  led_strip.clear();

  float next_led_weight = curr_min / 60.0;
  float curr_led_weight = 1.0 - next_led_weight;

  uint8_t r_base = COLOR_R * RED_STEPS;
  uint8_t g_base = COLOR_G * GREEN_STEPS;
  uint8_t b_base = COLOR_B * BLUE_STEPS;

  int curr_led = mod(curr_hour - HOUR_OFFSET, LED_COUNT);
  int next_led = mod(curr_hour - HOUR_OFFSET + 1, LED_COUNT);

  led_strip.setPixelColor(curr_led, led_strip.Color(
    (uint8_t)(r_base * curr_led_weight), 
    (uint8_t)(g_base * curr_led_weight), 
    (uint8_t)(b_base * curr_led_weight)
  ));

  led_strip.setPixelColor(next_led, led_strip.Color(
    (uint8_t)(r_base * next_led_weight), 
    (uint8_t)(g_base * next_led_weight), 
    (uint8_t)(b_base * next_led_weight)
  ));

  led_strip.show();

#if SET_DBG == true
  Serial.println(F("Hour now: "));
  Serial.print(curr_hour);
  Serial.println(F("\nMin now: "));
  Serial.print(curr_min);
  Serial.print(F("\n"));

#endif
}

void upd_state() {
#if SET_DBG == true
  Serial.println(F("Configuring clock's LED.."));
#endif
  set_led_strip();
}

void upd_state_low_bat() {
#if SET_DBG == true
  Serial.println(F("Configuring clock's LED.."));
#endif
  set_led_strip();
  digitalWrite(BAT_LED_PIN, 1); // pulse builtin LED
  delay(1000);
  led_strip.clear();
  led_strip.show();
  delay(1000);
}

void setup()
{
  Wire.begin();
  configure_rtc();
#if SET_DBG == true
  Serial.begin(SERIAL_BAUD_RATE);
#endif
#if SET_TIME == true
  set_time();
#endif
  led_strip.begin();
  led_strip.setBrightness(20);
  set_bod_config();
  delay(2000);
  select_adc_res();
  select_bandgap();
}

void loop()
{
  if (analogRead(PIN_BAT) < LOW_BAT_THRESH) {
    upd_state_low_bat();
  } else {
    upd_state();
  }
  delay(10000);
}

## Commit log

2026-03-26 add project and model files
    [USB_type_C_smd_6p.stp, bookmark_body.dxf, bookmark_v1.blend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]
2026-03-28 fix: correct LED footprints
    [project.kicad_pcb, project.kicad_sch]
2026-03-28 fix: fix wrong UPDI & DBG pin label
    [controller.kicad_pcb, controller.kicad_sch]
2026-03-29 chore: rename model/ to mockup/
    [USB_type_C_smd_6p.stp, bookmark_body.dxf, bookmark_v1.blend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]
2026-03-29 fix: make sense of the connection from power to peripherals make the DS3231 get power directly without a switch and add testing pads to connect power to MCU & LEDs in order to measure current.
    [controller.kicad_pcb, controller.kicad_sch]
2026-03-29 revert 6c72ed
    [controller.kicad_pcb]
2026-03-29 clean up position of footprints
    [controller.kicad_pcb, controller.kicad_sch]
2026-03-29 do not track backup files
2026-03-29 do not track unimportant kicad project files
    [project-B_Cu.gbr, project-B_Mask.gbr, project-B_Paste.gbr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]
2026-03-29 add freecad models
    [casing-clip.stl, casing.stl, lid.stl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]
2026-03-29 add pcb .step files
2026-05-09 change usb C footprint to USB-TYPE-C-006 https://jlcpcb.com/partdetail/DEALON-USB_TYPE_C006/C2927026
    [controller.kicad_pcb, controller.kicad_sch]
2026-05-10 fix(controller): change output directory
    [controller.kicad_pcb]
2026-05-10 remove drill files
    [project-NPTH.drl, project-PTH.drl]
2026-05-10 fix(bookmark): change 22uF value to 100uF cheapo. controller only uses 100uF and 0.1uF
    [project.kicad_pcb, project.kicad_sch]
2026-05-11 add BOM
    [bom.csv]
2026-05-11 bom: add anti-slip rubber
    [bom.csv]
2026-05-15 add BOM link
2026-05-15 fix(bom): add awg28 cable
    [bom.csv]
2026-05-15 fix(bom): add "1 set" to jst
    [bom.csv]
2026-05-15 fix(readme): add gerbers disclaimer
2026-06-11 fix(firmware): fix order of function definition
    [main.cpp]
2026-06-11 fix(firmware): fix pin used for battery voltage
    [cfg.h]
2026-06-11 fix(firmware): use digitalWrite instead of whatever digitalWriteFast is
    [main.cpp]
2026-06-11 fix(firmware): set sleep mode to idle
    to prevent getting locked up..
    [main.cpp]
2026-06-11 feat(firmware): add LED status before executing routine
2026-06-11 docs(firmware): fix system_power_down comment
    [main.cpp]
2026-06-12 fix function signature for modulo function
    [main.cpp]
2026-06-12 firmware: set new correct low battery thresh for the new voltage divider
    [cfg.h]
2026-06-12 fix(firmware): correct the code to select vref
    [main.cpp]
2026-06-12 fix(firmware): fix time setting function
    [main.cpp]
2026-06-12 firmware: remove interrupt pin definition
2026-06-12 firmware: add voltage divider notice
2026-06-12 firmware: add back battery low indicator no async running cuz im lazy this is just so i dont forget
2026-06-14 fix(firmware): fix LED not showing up
    [main.cpp]
2026-06-14 fix(firmware): light blend logic
    [main.cpp]
2026-06-15 feat(firmware): flash LED strip too when low battery
2026-06-15 fix(firmware): better doc for LOW_BAT_THRESH and set to 600
    [cfg.h]
2026-06-15 docs(firmware): remove bloated LED docs on cfg.h
2026-06-15 replace out of stock resistors with fresh ones * swap 1M+255K voltage divider to 787K+200K * swap 330 to 330 but less power rating the entire bom is now $0.1 cheaper!
    [bom.csv, controller.kicad_sch]
2026-06-15 update prices getting more expensive smh
    [bom.csv]
2026-06-15 change shipping method, remove hard-to-predict prices tax price calculation will go stale after i receive them anyway smh
    [bom.csv]
2026-06-15 add power usage
